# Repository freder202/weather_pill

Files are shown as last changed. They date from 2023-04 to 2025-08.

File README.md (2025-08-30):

### A small and compact weather logging station to use for outdoor adventures

The goal is to log the temperature, humidity, while having it displayed on a small lcd 

The battery life is expected to be 2 years on a CR2032

This is the Rev2, which is currently being tested as of August 2025
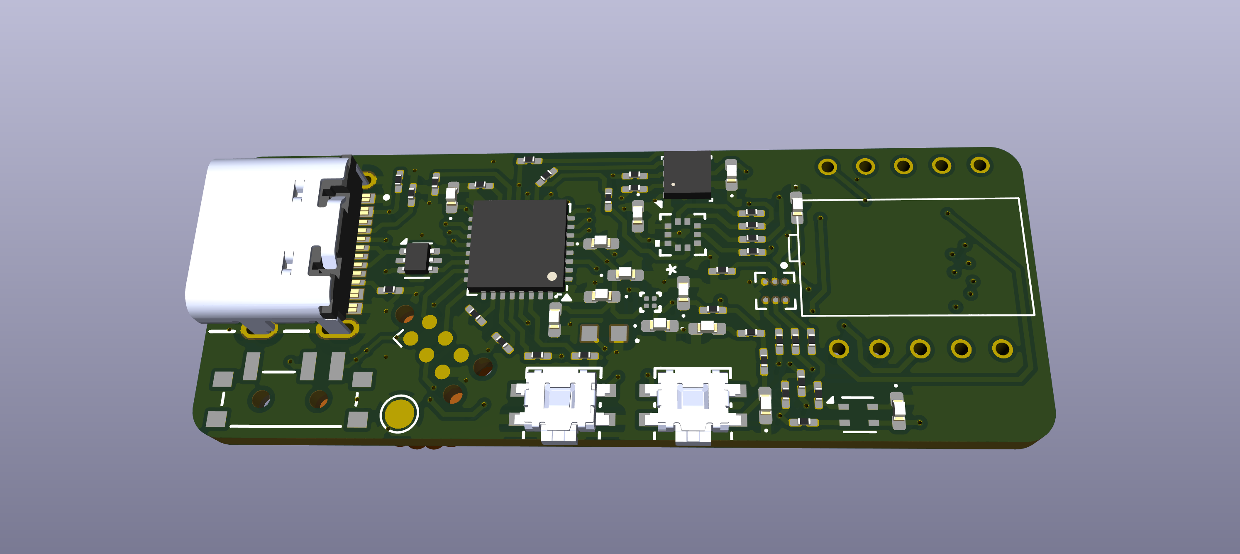
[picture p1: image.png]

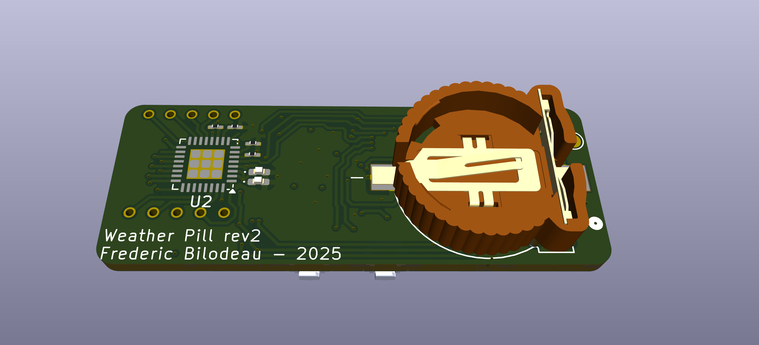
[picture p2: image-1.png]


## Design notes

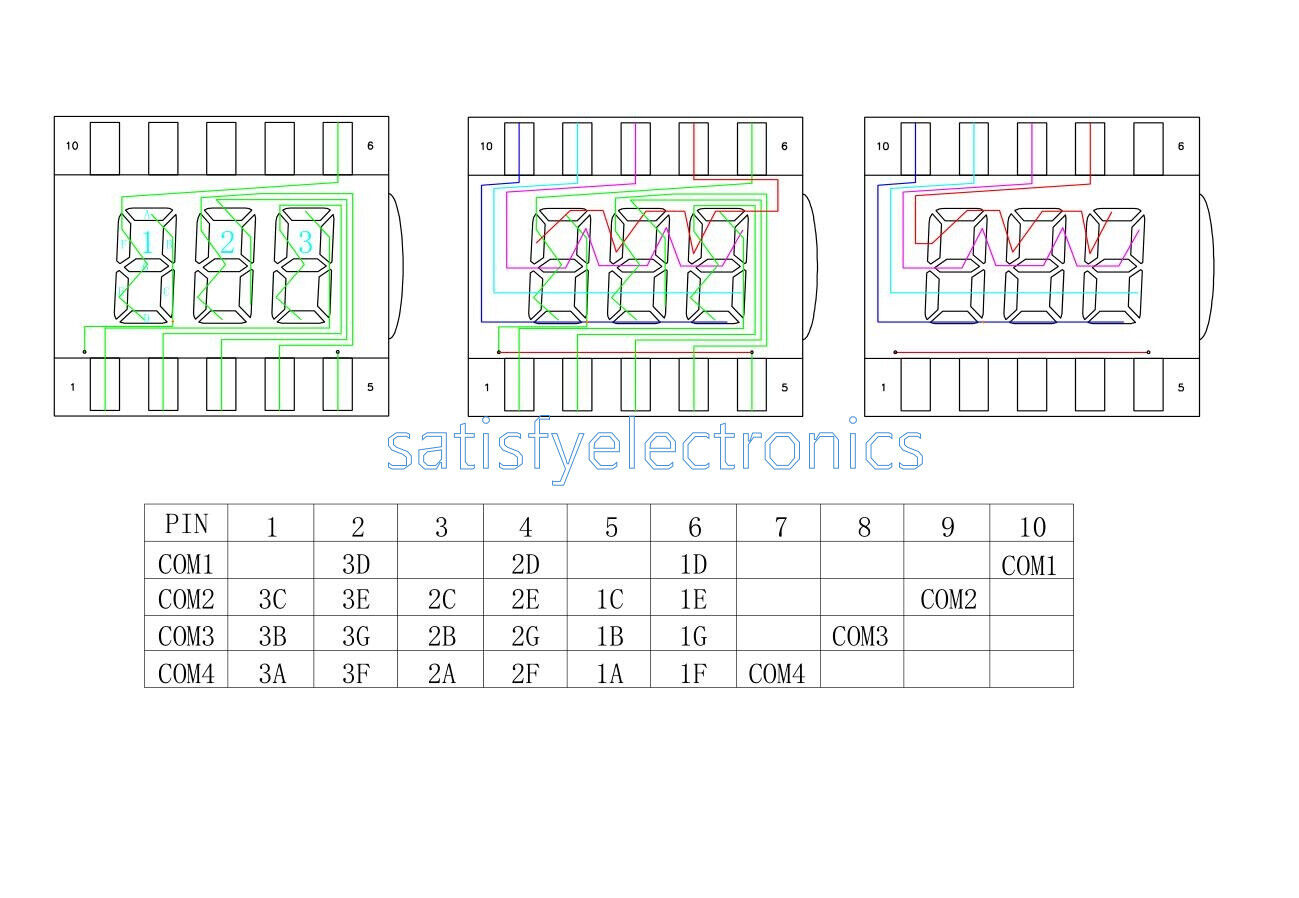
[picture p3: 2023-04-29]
WeatherPill/imported/s-l16003.jpg

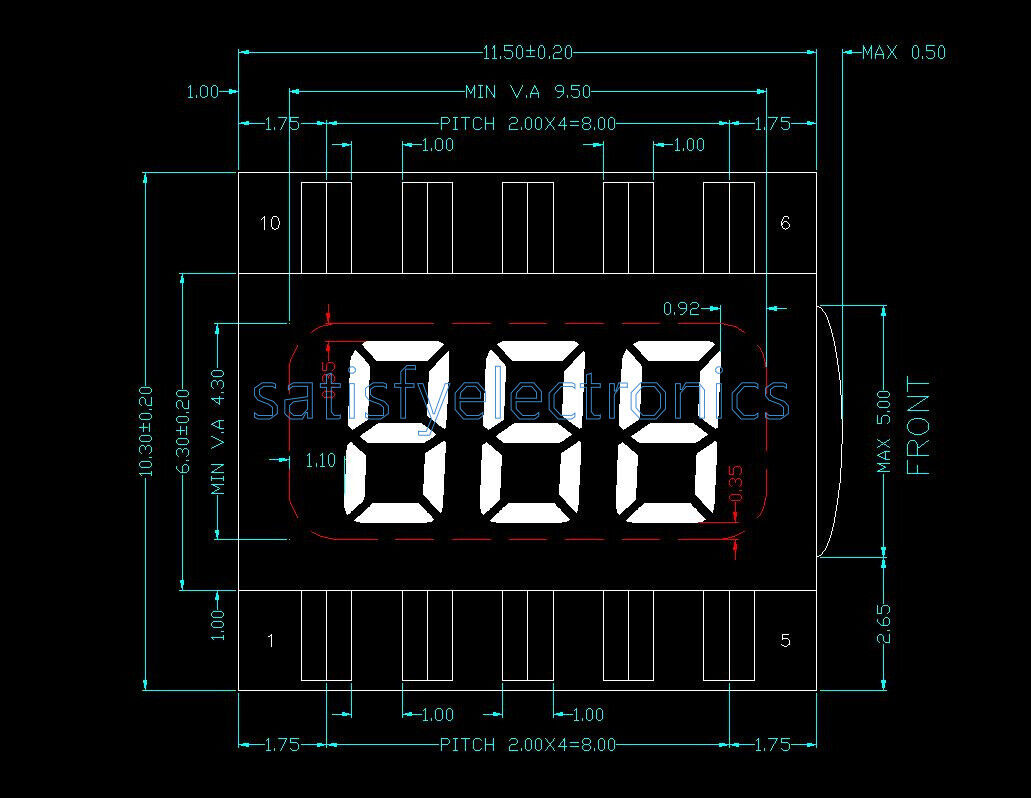
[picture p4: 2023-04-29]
WeatherPill/imported/s-l1600.jpg

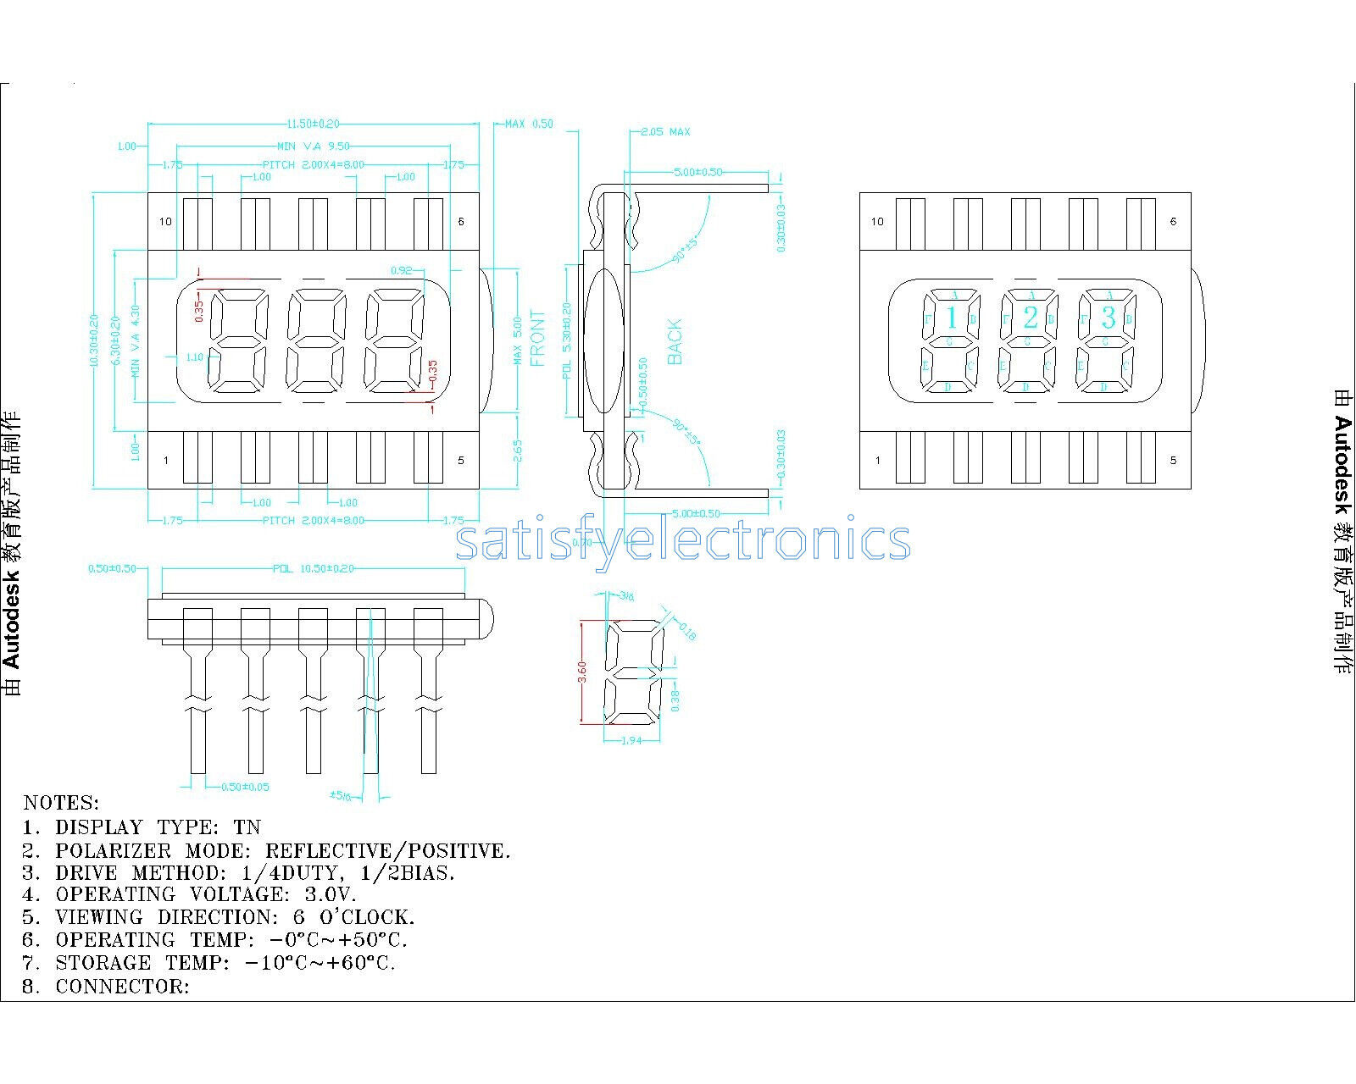
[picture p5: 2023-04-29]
WeatherPill/imported/s-l16002.jpg

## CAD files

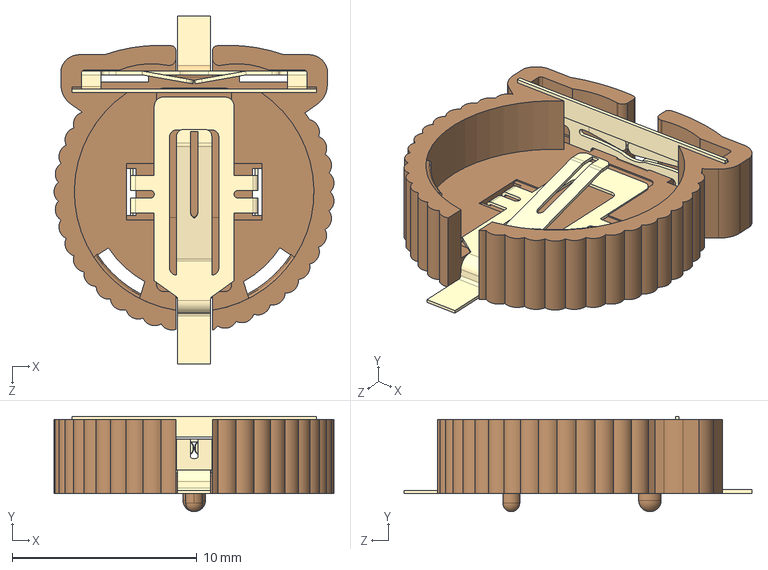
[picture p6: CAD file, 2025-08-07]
WeatherPill/imported/battery-12mm-holder/1056.step
15.1 x 5.16 x 18.8 mm

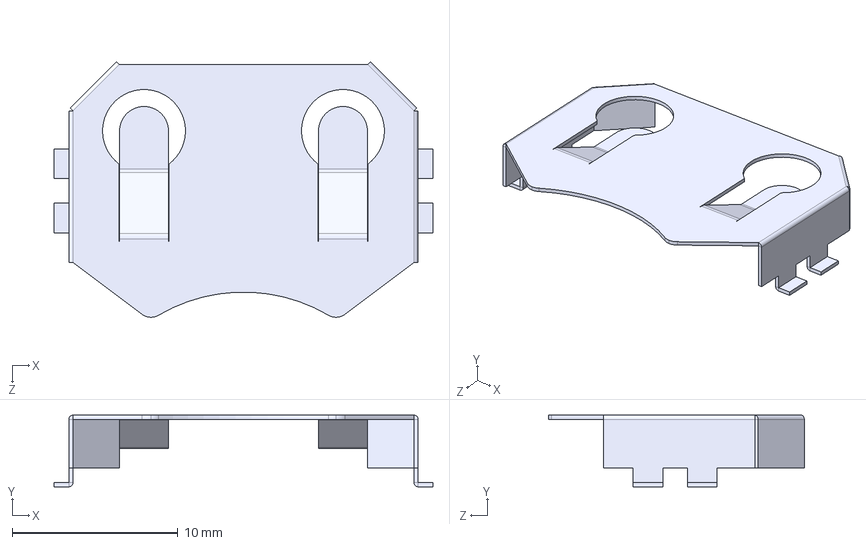
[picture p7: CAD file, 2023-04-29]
WeatherPill/imported/BK-912-TR/BK-912-TR.step
22.9 x 4.32 x 15.4 mm

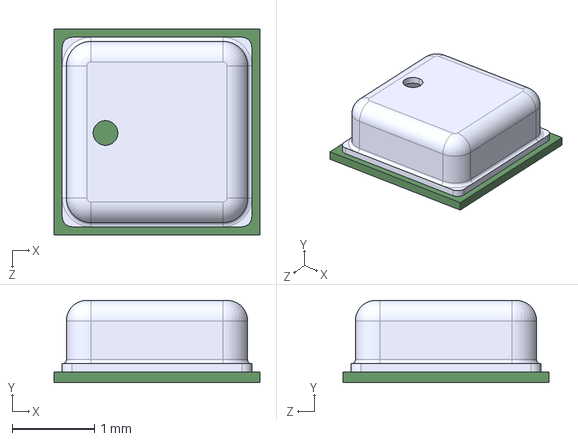
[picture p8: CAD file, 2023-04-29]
WeatherPill/imported/BME280/BME280.step
2.50 x 1.00 x 2.50 mm

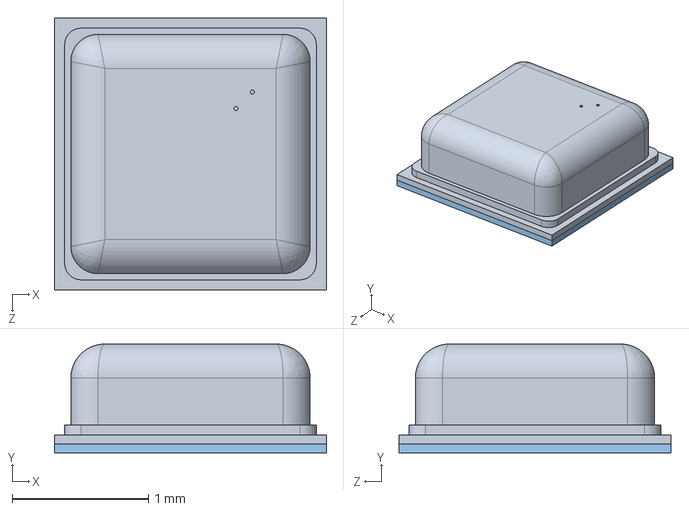
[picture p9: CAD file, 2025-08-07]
WeatherPill/imported/BMP581/BMP581.STEP
2.00 x 0.801 x 2.00 mm

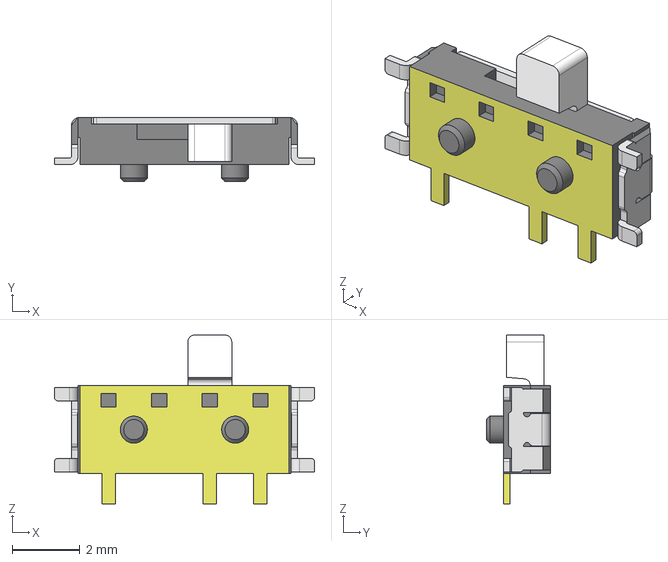
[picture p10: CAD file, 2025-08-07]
WeatherPill/imported/CUS_12TB/CUS-12TB.stp
7.70 x 1.90 x 5.00 mm
CUS-12-body
CUS-12-slider

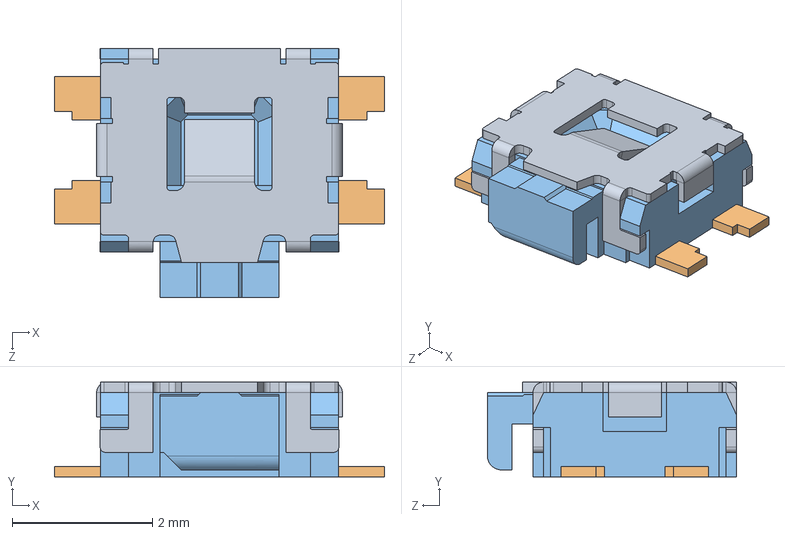
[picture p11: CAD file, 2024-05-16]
WeatherPill/imported/EVQ-P7A01P/EVQ-P7A01P.step
4.70 x 1.35 x 3.55 mm

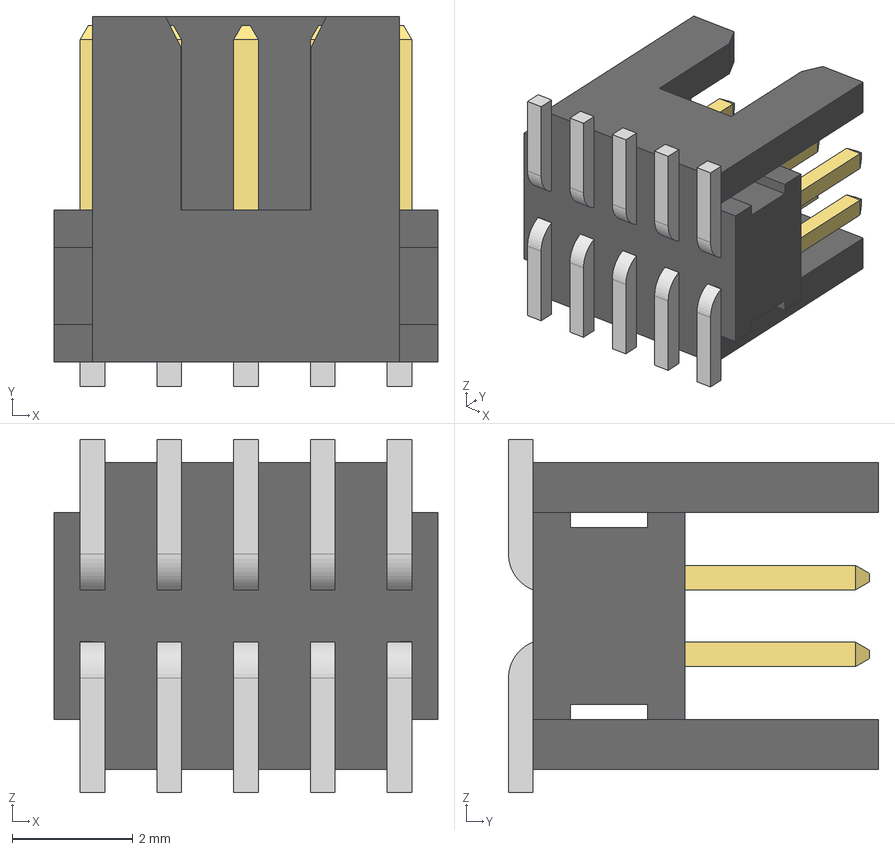
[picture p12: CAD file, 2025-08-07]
WeatherPill/imported/FTSH_105_01_L_DV_K_TR/FTSH-105-XX-X-DV.step
6.35 x 6.12 x 5.84 mm
FTSH-105-01-L-DV-K-TR_body
FTSH-105-01-L-DV-K-TR_pins1
FTSH-105-01-L-DV-K-TR_pins2

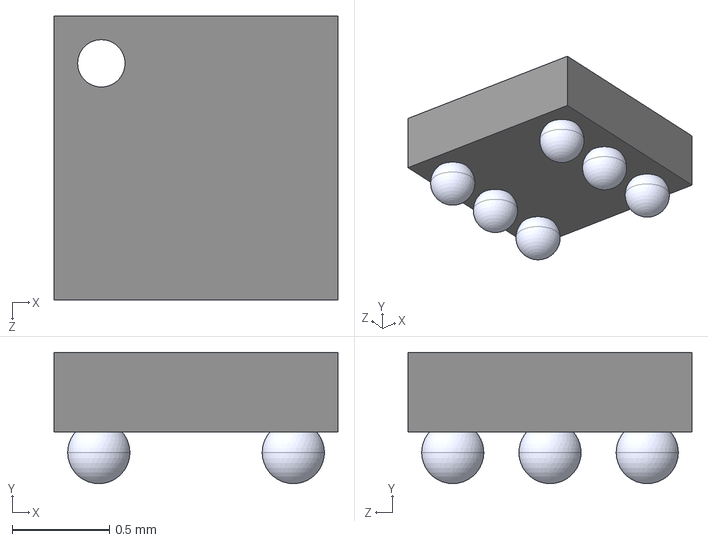
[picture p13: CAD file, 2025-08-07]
WeatherPill/imported/HDC2010YPAR/HDC2010YPAR.step
1.46 x 0.675 x 1.46 mm

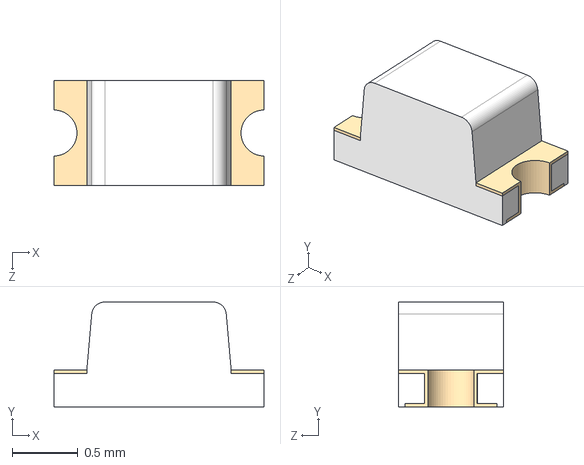
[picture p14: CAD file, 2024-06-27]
WeatherPill/imported/led green/LTST-C190GKT.step
1.60 x 0.8 x 0.8 mm

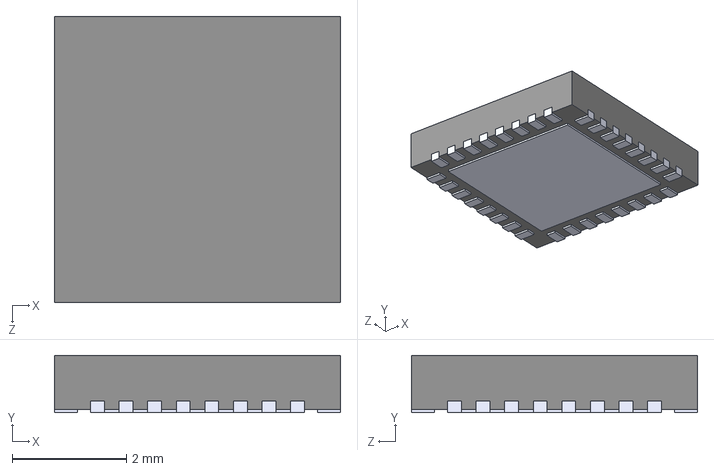
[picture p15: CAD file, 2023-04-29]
WeatherPill/imported/QFN50P500X500X100-33N.step
5.00 x 1 x 5.00 mm

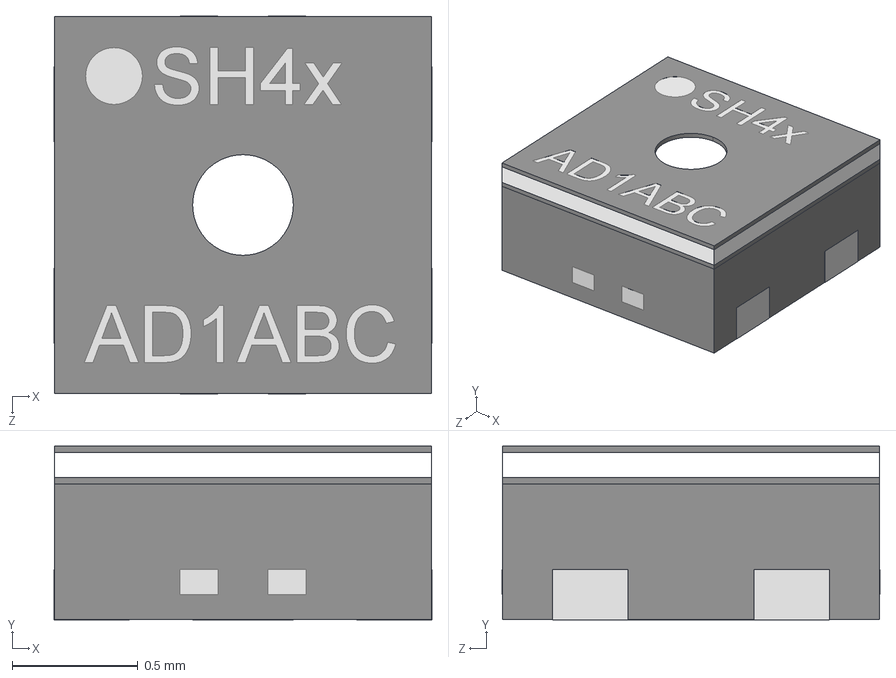
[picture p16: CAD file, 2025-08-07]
WeatherPill/imported/SHT45_AD1F_R2/SHT45-AD1F-R2.step
1.50 x 0.691 x 1.50 mm

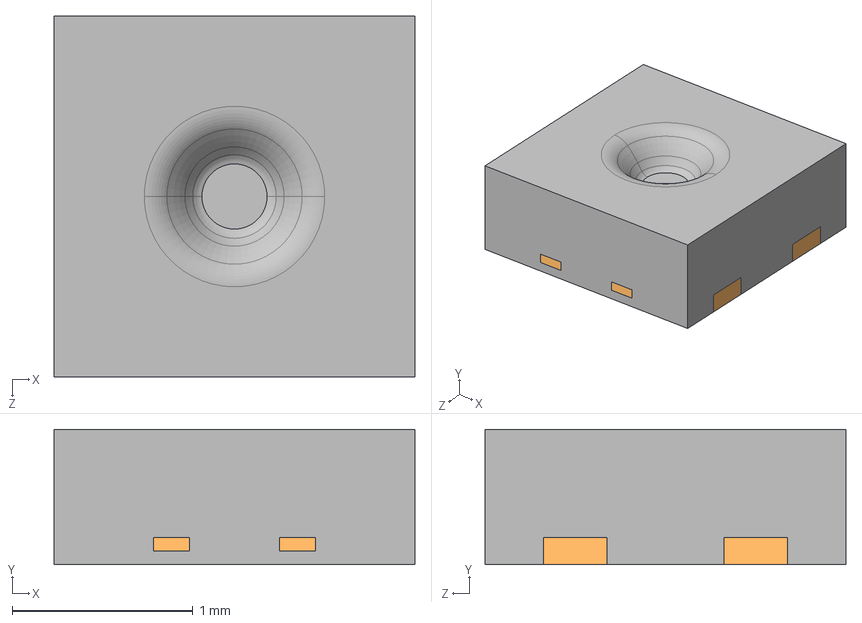
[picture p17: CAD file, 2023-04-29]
WeatherPill/imported/SHTC3/SHTC3.step
2.00 x 0.75 x 2.00 mm

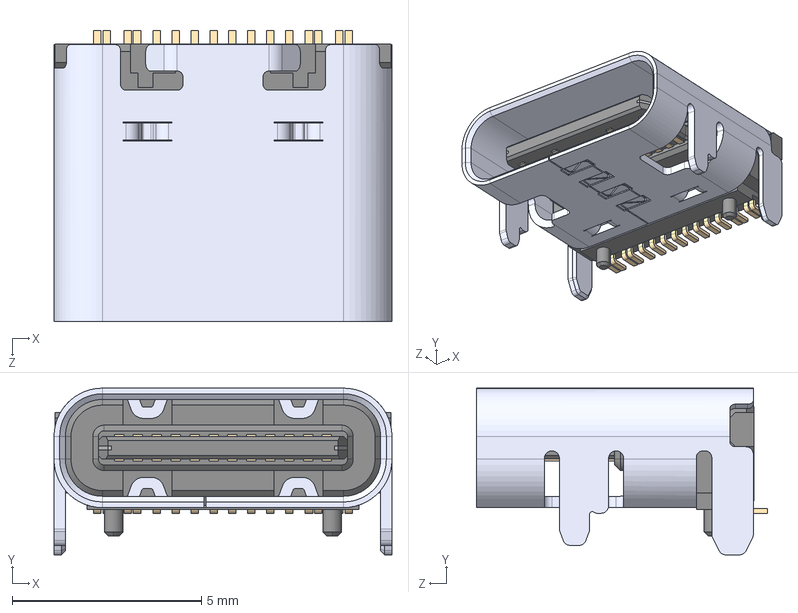
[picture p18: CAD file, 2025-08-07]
WeatherPill/imported/USB4105_GF_A/USB4105-GF-A.step
8.94 x 4.41 x 7.71 mm

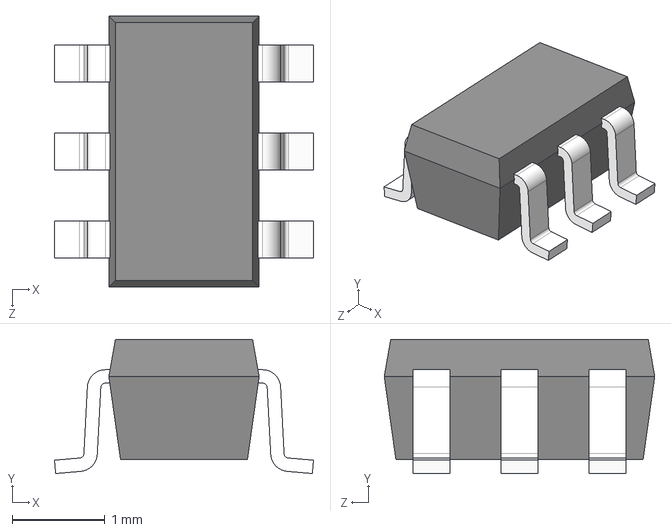
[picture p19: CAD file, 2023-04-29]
WeatherPill/imported/USBLC6-2SC6/USBLC6-2SC6.step
2.80 x 1.45 x 2.92 mm

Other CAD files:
WeatherPill/imported/USBLC6_2P6/USBLC6-2P6.step
WeatherPill/imported/EVQ-P7A01P/EVQ-P7A01P--3DModel-STEP-269445.STEP
WeatherPill/imported/TPS22916CYFPR/TPS22916CYFPR.step
WeatherPill/imported/USB12402012E212A/12402012E212A--3DModel-STEP-533217.STEP

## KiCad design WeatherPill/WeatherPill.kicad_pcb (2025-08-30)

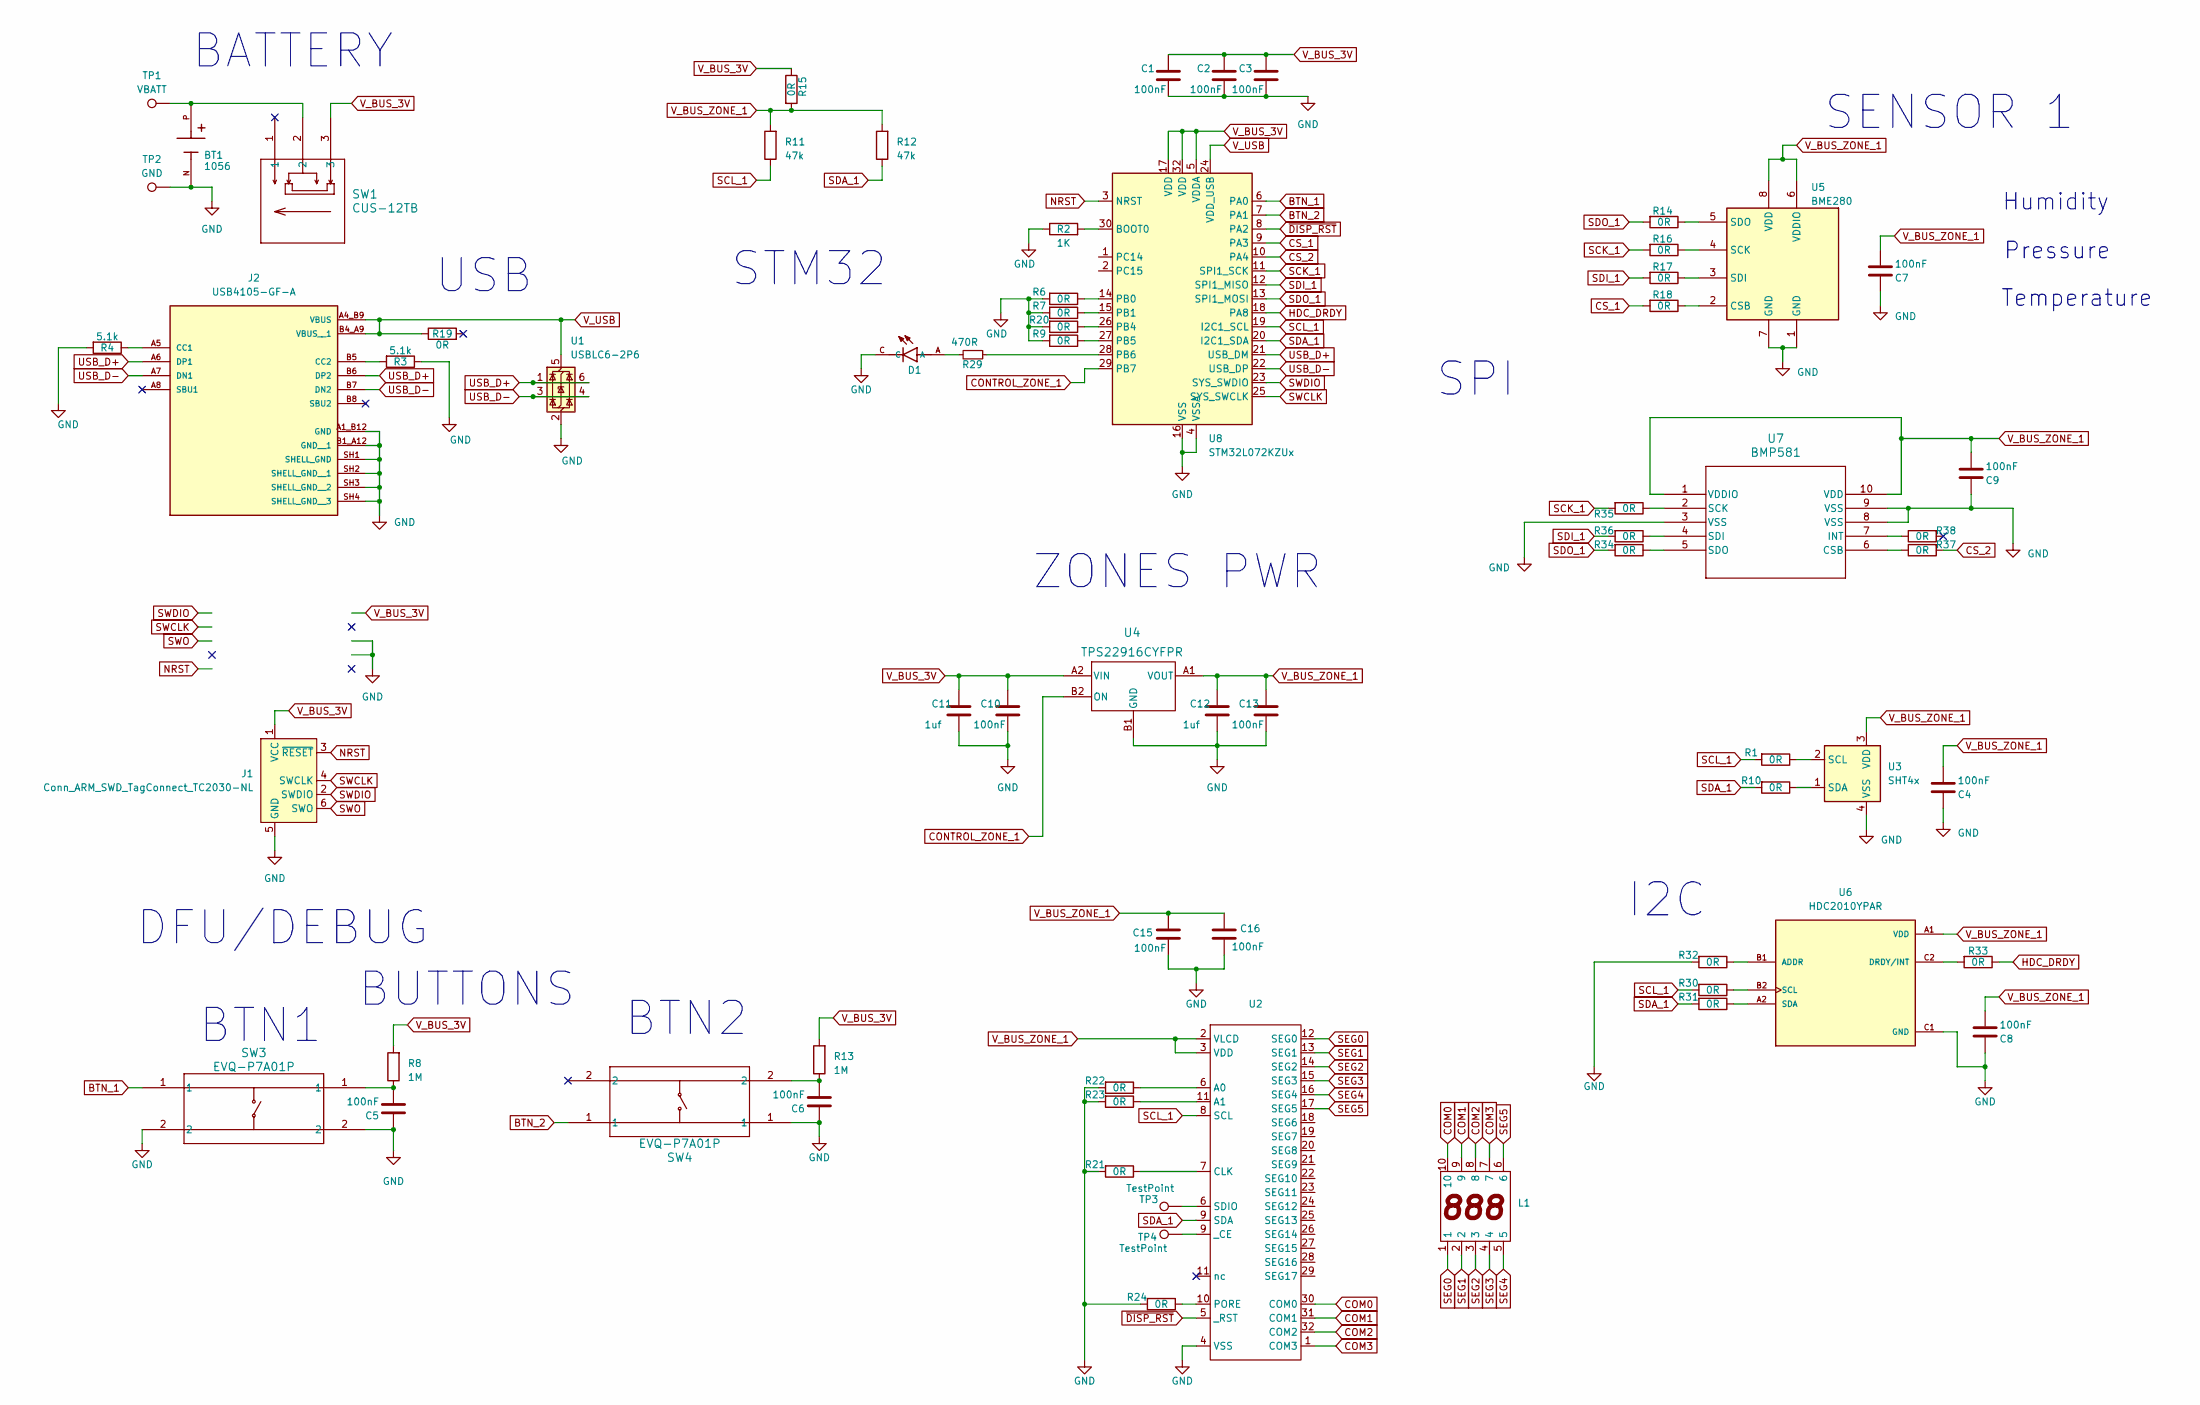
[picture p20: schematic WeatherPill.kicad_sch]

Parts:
BT1: 1056; BAT_1056; PARTREV D
C1, C2, C3, C4, C5, C6, C7, C8, C9, C10, C13, C15, C16: 100nF; LED_0402_1005Metric_Pad0.77x0.64mm_HandSolder
C11, C12: 1uf; LED_0402_1005Metric_Pad0.77x0.64mm_HandSolder
D1: LTST-C190GKT; LEDM1608X80
J1: Conn_ARM_SWD_TagConnect_TC2030-NL; Tag-Connect_TC2030-IDC-NL_2x03_P1.27mm_Vertical
J2: USB4105-GF-A; GCT_USB4105-GF-A; PARTREV B4
L1: INND-SS30
R1, R6, R7, R9, R10, R14, R15, R16, R17, R18, R19, R20, R21, R22, R23, R24, R30, R31, R32, R33, R34, R35, R36, R37, R38: 0R; R_0201_0603Metric_Pad0.64x0.40mm_HandSolder
R2: 1K; R_0201_0603Metric_Pad0.64x0.40mm_HandSolder
R3, R4: 5.1k; R_0201_0603Metric_Pad0.64x0.40mm_HandSolder
R8, R13: 1M; R_0201_0603Metric_Pad0.64x0.40mm_HandSolder
R11, R12: 47k; R_0201_0603Metric_Pad0.64x0.40mm_HandSolder
R29: 470R; R_0201_0603Metric_Pad0.64x0.40mm_HandSolder
SW1: CUS-12TB; CUS-12TB_NDC
SW3, SW4: EVQ-P7A01P; EVQ_P7_PAN
TP1: VBATT; TestPoint_Pad_D1.5mm
TP2: GND; TestPoint_Pad_D1.5mm
TP3, TP4: TestPoint
U1: USBLC6-2P6; SOT-666
U2: HVQFN-32-1EP_5x5mm_P0.5mm_EP3.1x3.1mm
U3: SHT4x; Sensirion_DFN-4_1.5x1.5mm_P0.8mm_SHT4x_NoCentralPad
U4: TPS22916CYFPR; YFP0004ABAB
U5: BME280; Bosch_LGA-8_2.5x2.5mm_P0.65mm_ClockwisePinNumbering
U6: HDC2010YPAR; BGA6C100X50P2X3_HDC2010YPAR; PARTREV C
U7: BMP581; QFN10_BMP581_BOS-M
U8: STM32L072KZUx; QFN-32-1EP_5x5mm_P0.5mm_EP3.45x3.45mm

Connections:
COM0: L1.10, U2.30 (COM0)
COM1: L1.9, U2.31 (COM1)
COM2: L1.8, U2.32 (COM2)
COM3: L1.7, U2.1 (COM3)
CONTROL_ZONE_1: U4.B2 (ON), U8.29 (PB7)
CS_1: R18.2, U8.9 (PA3)
CS_2: R37.2, U8.10 (PA4)
HDC_DRDY: R33.1, U8.18 (PA8)
NRST: J1.3 (~RESET), U8.3 (NRST)
unnamed: BT1.P, SW1.2, TP1.1
unnamed: C6.2, R13.1, SW4.2
unnamed: D1.A, R29.2
unnamed: J2.A5 (CC1), R4.1
unnamed: J2.B5 (CC2), R3.2
unnamed: R22.1, TP3.1, U2.6 (A0)
unnamed: R23.1, U2.11 (A1)
unnamed: R21.1, U2.7 (CLK)
unnamed: R24.1, U2.10 (PORE)
unnamed: R1.1, U3.2 (SCL)
unnamed: R10.1, U3.1 (SDA)
unnamed: R18.1, U5.2 (CSB)
unnamed: R16.1, U5.4 (SCK)
unnamed: R17.1, U5.3 (SDI)
unnamed: R14.1, U5.5 (SDO)
unnamed: R32.1, U6.B1 (ADDR)
unnamed: R33.2, U6.C2 (DRDY/INT)
unnamed: R30.1, U6.B2 (SCL)
unnamed: R31.1, U6.A2 (SDA)
unnamed: R37.1, U7.6 (CSB)
unnamed: R38.1, U7.7 (INT)
unnamed: R35.1, U7.2 (SCK)
unnamed: R36.1, U7.4 (SDI)
unnamed: R34.1, U7.5 (SDO)
unnamed: R2.2, U8.30 (BOOT0)
unnamed: R6.1, U8.14 (PB0)
unnamed: R7.1, U8.15 (PB1)
unnamed: R20.1, U8.26 (PB4)
unnamed: R9.1, U8.27 (PB5)
unnamed: R29.1, U8.28 (PB6)
SCK_1: R16.2, R35.2, U8.11 (SPI1_SCK)
SCL_1: R1.2, R11.1, R30.2, U2.8 (SCL), U8.19 (I2C1_SCL)
SDI_1: R17.2, R36.2, U8.12 (SPI1_MISO)
SDO_1: R14.2, R34.2, U8.13 (SPI1_MOSI)
SEG0: L1.1, U2.12 (SEG0)
SEG1: L1.2, U2.13 (SEG1)
SEG2: L1.3, U2.14 (SEG2)
SEG3: L1.4, U2.15 (SEG3)
SEG4: L1.5, U2.16 (SEG4)
SEG5: L1.6, U2.17 (SEG5)
SWCLK: J1.4 (SWCLK), U8.25 (SYS_SWCLK)
SWDIO: J1.2 (SWDIO), U8.23 (SYS_SWDIO)
SWO: J1.6 (SWO)
USB_D+: J2.A6 (DP1), J2.B6 (DP2), U1.1 (I/O1), U1.6 (I/O1), U8.21 (USB_DM)
USB_D-: J2.A7 (DN1), J2.B7 (DN2), U1.3 (I/O2), U1.4 (I/O2), U8.22 (USB_DP)
V_BUS_3V: C1.1, C2.1, C3.1, C10.1, C11.1, J1.1 (VCC), R8.2, R13.2, R15.1, SW1.3, U4.A2 (VIN), U8.5 (VDDA), U8.17 (VDD), U8.32 (VDD)
V_BUS_ZONE_1: C4.2, C7.2, C8.2, C9.2, C12.1, C13.1, C15.1, C16.1, R11.2, R12.2, R15.2, U2.2 (VLCD), U2.3 (VDD), U3.3 (VDD), U4.A1 (VOUT), U5.6 (VDDIO), U5.8 (VDD), U6.A1 (VDD), U7.1 (VDDIO), U7.10 (VDD)
V_USB: J2.A4_B9 (VBUS), J2.B4_A9 (VBUS__1), R19.1, U1.5 (VBUS), U8.24 (VDD_USB)
~DISP_RST: U2.5 (_RST), U8.8 (PA2)

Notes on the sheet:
DFU/DEBUG
Pressure
ZONES PWR
I2C
BTN1
Temperature
USB
BTN2
SPI
STM32
BATTERY
SENSOR 1
BUTTONS
Humidity

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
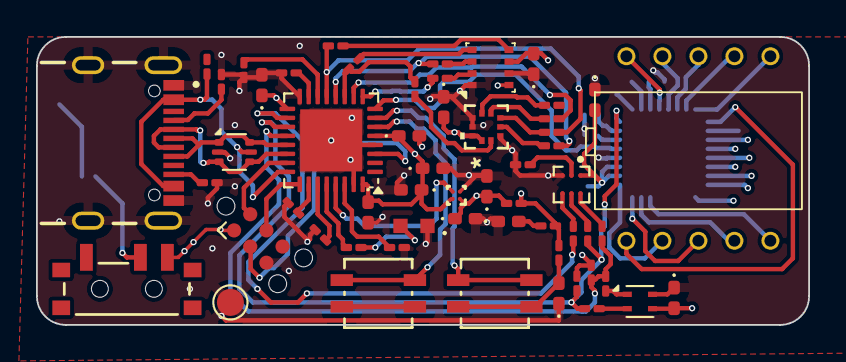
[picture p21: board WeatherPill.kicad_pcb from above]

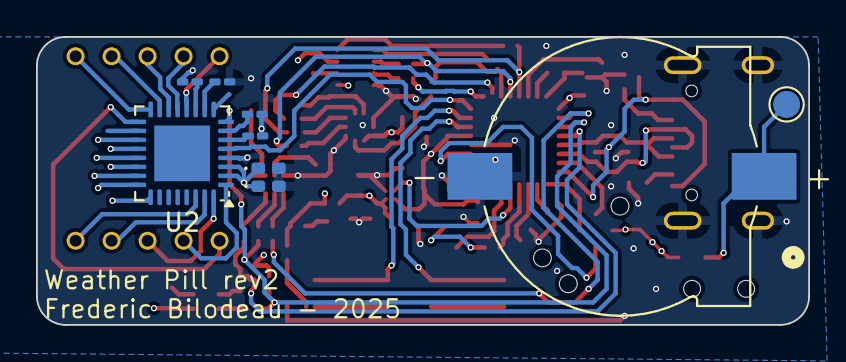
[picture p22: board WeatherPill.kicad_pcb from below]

Board: 4 copper layers, 42.9 x 16.0 mm, 66 parts (9 on the bottom side), 62 nets.

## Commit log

2023-04-29 stating to configs pins
    [WeatherPill.kicad_pcb, WeatherPill.kicad_sch]
2023-06-12 in review
    [12402012E212A--3DModel-STEP-533217.STEP, USB4125-GF-A_REVA2.step, WeatherPill.csv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]
2024-05-16 revision 2
    [EVQ-P7A01P.step, WeatherPill.kicad_pcb, WeatherPill.kicad_sch]
2024-06-13 fred: update pcb
    [WeatherPill.kicad_pcb, WeatherPill.kicad_sch]
2024-06-27 fred: avancements
    [LTST-C190GKT.step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]
2025-08-07 V2 cooking
    [1056.step, BMP581.STEP, CUS-12TB.stp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]
2025-08-30 rev 2 sent
    [WeatherPill.kicad_pcb, WeatherPill.kicad_sch]
2025-08-30 errata sent v2
    [WeatherPill-B_Cu.gbr, WeatherPill-B_Mask.gbr, WeatherPill-B_Paste.gbr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]

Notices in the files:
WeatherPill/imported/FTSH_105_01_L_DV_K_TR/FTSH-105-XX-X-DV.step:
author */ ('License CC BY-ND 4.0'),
